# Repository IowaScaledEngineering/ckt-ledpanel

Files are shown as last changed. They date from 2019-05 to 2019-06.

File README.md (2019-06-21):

# CKT-LEDPANEL
Lithion Ion Battery-Powered Constant Current LED Boost Driver for Light Panel

## Project Background

Back in 2018, I came up with the idea for a battery-powered backlit display
cabinet to take with me to insulator shows.  The traditional solutions were
heavy cabinets with fluorescent tubes and ballasts that required line power.
By combining side-lit LED light panels intended for drop ceilings and high capacity lithium ion tool
batteries, building a small, light cabinet that would run entirely on battery power
was well within reach.

The CKT-LEDPANEL will drive a standard 30-38V panel at 300mA, which is more
than bright enough for a cabinet backlight.  It includes safety circuits to
prevent over-discharge of "20V" (5 series cell) lithium ion tool batteries,
such as those available from Dewalt.  It also provides convenient connectors
for an on/off switch and an 18VDC wall power supply input.

## Cabinet Construction Instructions

Instructions for constructing the cabinets and wiring everything up
(including the CKT-LEDPANEL) can be found [on my personal
website](https://www.ndholmes.com/projects/ins-cabinet/ins-cab-instructions-v1.0.pdf).

## License

The CKT-LEDPANEL is copyright 2019 by Nathan Holmes and Michael Petersen and manufactured by Iowa
Scaled Engineering.  The design is open hardware, and is shared under the
[Creative Commons Attribution-Share Alike
license](https://creativecommons.org/licenses/by-sa/4.0/legalcode).

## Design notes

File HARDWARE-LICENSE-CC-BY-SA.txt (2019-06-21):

The hardware design files for the Iowa Scaled Engineering I2C-RELAY16 are
open hardware, and licensed under the Creative Commons Attribution-Share
Alike license.

A copy can be found below, or from 
  http://creativecommons.org/licenses/by-sa/4.0/legalcode
-----------------------------------------------------------------------------

Creative Commons Attribution-ShareAlike 4.0 International Public License

By exercising the Licensed Rights (defined below), You accept and agree to
be bound by the terms and conditions of this Creative Commons
Attribution-ShareAlike 4.0 International Public License ("Public License").
To the extent this Public License may be interpreted as a contract, You are
granted the Licensed Rights in consideration of Your acceptance of these
terms and conditions, and the Licensor grants You such rights in
consideration of benefits the Licensor receives from making the Licensed
Material available under these terms and conditions.

Section 1 – Definitions.

    Adapted Material means material subject to Copyright and Similar Rights
that is derived from or based upon the Licensed Material and in which the
Licensed Material is translated, altered, arranged, transformed, or
otherwise modified in a manner requiring permission under the Copyright and
Similar Rights held by the Licensor. For purposes of this Public License,
where the Licensed Material is a musical work, performance, or sound
recording, Adapted Material is always produced where the Licensed Material
is synched in timed relation with a moving image.
    Adapter's License means the license You apply to Your Copyright and
Similar Rights in Your contributions to Adapted Material in accordance with
the terms and conditions of this Public License.
    BY-SA Compatible License means a license listed at
creativecommons.org/compatiblelicenses, approved by Creative Commons as
essentially the equivalent of this Public License.
    Copyright and Similar Rights means copyright and/or similar rights
closely related to copyright including, without limitation, performance,
broadcast, sound recording, and Sui Generis Database Rights, without regard
to how the rights are labeled or categorized. For purposes of this Public
License, the rights specified in Section 2(b)(1)-(2) are not Copyright and
Similar Rights.
    Effective Technological Measures means those measures that, in the
absence of proper authority, may not be circumvented under laws fulfilling
obligations under Article 11 of the WIPO Copyright Treaty adopted on
December 20, 1996, and/or similar international agreements.
    Exceptions and Limitations means fair use, fair dealing, and/or any
other exception or limitation to Copyright and Similar Rights that applies
to Your use of the Licensed Material.
    License Elements means the license attributes listed in the name of a
Creative Commons Public License. The License Elements of this Public License
are Attribution and ShareAlike.
    Licensed Material means the artistic or literary work, database, or
other material to which the Licensor applied this Public License.
    Licensed Rights means the rights granted to You subject to the terms and
conditions of this Public License, which are limited to all Copyright and
Similar Rights that apply to Your use of the Licensed Material and that the
Licensor has authority to license.
    Licensor means the individual(s) or entity(ies) granting rights under
this Public License.
    Share means to provide material to the public by any means or process
that requires permission under the Licensed Rights, such as reproduction,
public display, public performance, distribution, dissemination,
communication, or importation, and to make material available to the public
including in ways that members of the public may access the material from a
place and at a time individually chosen by them.
    Sui Generis Database Rights means rights other than copyright resulting
from Directive 96/9/EC of the European Parliament and of the Council of 11
March 1996 on the legal protection of databases, as amended and/or
succeeded, as well as other essentially equivalent rights anywhere in the
world.
    You means the individual or entity exercising the Licensed Rights under
this Public License. Your has a corresponding meaning.

Section 2 – Scope.

    License grant.
        Subject to the terms and conditions of this Public License, the
Licensor hereby grants You a worldwide, royalty-free, non-sublicensable,
non-exclusive, irrevocable license to exercise the Licensed Rights in the
Licensed Material to:
            reproduce and Share the Licensed Material, in whole or in part;
and
            produce, reproduce, and Share Adapted Material.
        Exceptions and Limitations. For the avoidance of doubt, where
Exceptions and Limitations apply to Your use, this Public License does not
apply, and You do not need to comply with its terms and conditions.
        Term. The term of this Public License is specified in Section 6(a).
        Media and formats; technical modifications allowed. The Licensor
authorizes You to exercise the Licensed Rights in all media and formats
whether now known or hereafter created, and to make technical modifications
necessary to do so. The Licensor waives and/or agrees not to assert any
right or authority to forbid You from making technical modifications
necessary to exercise the Licensed Rights, including technical modifications
necessary to circumvent Effective Technological Measures. For purposes of
this Public License, simply making modifications authorized by this Section
2(a)(4) never produces Adapted Material.
        Downstream recipients.
            Offer from the Licensor – Licensed Material. Every recipient of
the Licensed Material automatically receives an offer from the Licensor to
exercise the Licensed Rights under the terms and conditions of this Public
License.
            Additional offer from the Licensor – Adapted Material. Every
recipient of Adapted Material from You automatically receives an offer from
the Licensor to exercise the Licensed Rights in the Adapted Material under
the conditions of the Adapter’s License You apply.
            No downstream restrictions. You may not offer or impose any
additional or different terms or conditions on, or apply any Effective
Technological Measures to, the Licensed Material if doing so restricts
exercise of the Licensed Rights by any recipient of the Licensed Material.
        No endorsement. Nothing in this Public License constitutes or may be
construed as permission to assert or imply that You are, or that Your use of
the Licensed Material is, connected with, or sponsored, endorsed, or granted
official status by, the Licensor or others designated to receive attribution
as provided in Section 3(a)(1)(A)(i).

    Other rights.
        Moral rights, such as the right of integrity, are not licensed under
this Public License, nor are publicity, privacy, and/or other similar
personality rights; however, to the extent possible, the Licensor waives
and/or agrees not to assert any such rights held by the Licensor to the
limited extent necessary to allow You to exercise the Licensed Rights, but
not otherwise.
        Patent and trademark rights are not licensed under this Public
License.
        To the extent possible, the Licensor waives any right to collect
royalties from You for the exercise of the Licensed Rights, whether directly
or through a collecting society under any voluntary or waivable statutory or
compulsory licensing scheme. In all other cases the Licensor expressly
reserves any right to collect such royalties.

Section 3 – License Conditions.

Your exercise of the Licensed Rights is expressly made subject to the
following conditions.

    Attribution.

        If You Share the Licensed Material (including in modified form), You
must:
            retain the following if it is supplied by the Licensor with the
Licensed Material:
                identification of the creator(s) of the Licensed Material
and any others designated to receive attribution, in any reasonable manner
requested by the Licensor (including by pseudonym if designated);
                a copyright notice;
                a notice that refers to this Public License;
                a notice that refers to the disclaimer of warranties;
                a URI or hyperlink to the Licensed Material to the extent
                reasonably practicable;
            indicate if You modified the Licensed Material and retain an
indication of any previous modifications; and
            indicate the Licensed Material is licensed under this Public
License, and include the text of, or the URI or hyperlink to, this Public
License.
        You may satisfy the conditions in Section 3(a)(1) in any reasonable
manner based on the medium, means, and context in which You Share the
Licensed Material. For example, it may be reasonable to satisfy the
conditions by providing a URI or hyperlink to a resource that includes the
required information.
        If requested by the Licensor, You must remove any of the information
required by Section 3(a)(1)(A) to the extent reasonably practicable.
    ShareAlike.

    In addition to the conditions in Section 3(a), if You Share Adapted
Material You produce, the following conditions also apply.
        The Adapter’s License You apply must be a Creative Commons license
with the same License Elements, this version or later, or a BY-SA Compatible
License.
        You must include the text of, or the URI or hyperlink to, the
Adapter's License You apply. You may satisfy this condition in any
reasonable manner based on the medium, means, and context in which You Share
Adapted Material.
        You may not offer or impose any additional or different terms or
conditions on, or apply any Effective Technological Measures to, Adapted
Material that restrict exercise of the rights granted under the Adapter's
License You apply.

Section 4 – Sui Generis Database Rights.

Where the Licensed Rights include Sui Generis Database Rights that apply to
Your use of the Licensed Material:

    for the avoidance of doubt, Section 2(a)(1) grants You the right to
extract, reuse, reproduce, and Share all or a substantial portion of the
contents of the database;
    if You include all or a substantial portion of the database contents in
a database in which You have Sui Generis Database Rights, then the database
in which You have Sui Generis Database Rights (but not its individual
contents) is Adapted Material, including for purposes of Section 3(b); and
    You must comply with the conditions in Section 3(a) if You Share all or
a substantial portion of the contents of the database.

For the avoidance of doubt, this Section 4 supplements and does not replace
Your obligations under this Public License where the Licensed Rights include
other Copyright and Similar Rights.

Section 5 – Disclaimer of Warranties and Limitation of Liability.

    Unless otherwise separately undertaken by the Licensor, to the extent
possible, the Licensor offers the Licensed Material as-is and as-available,
and makes no representations or warranties of any kind concerning the
Licensed Material, whether express, implied, statutory, or other. This
includes, without limitation, warranties of title, merchantability, fitness
for a particular purpose, non-infringement, absence of latent or other
defects, accuracy, or the presence or absence of errors, whether or not
known or discoverable. Where disclaimers of warranties are not allowed in
full or in part, this disclaimer may not apply to You.
    To the extent possible, in no event will the Licensor be liable to You
on any legal theory (including, without limitation, negligence) or otherwise
for any direct, special, indirect, incidental, consequential, punitive,
exemplary, or other losses, costs, expenses, or damages arising out of this
Public License or use of the Licensed Material, even if the Licensor has
been advised of the possibility of such losses, costs, expenses, or damages.
Where a limitation of liability is not allowed in full or in part, this
limitation may not apply to You.

    The disclaimer of warranties and limitation of liability provided above
shall be interpreted in a manner that, to the extent possible, most closely
approximates an absolute disclaimer and waiver of all liability.

Section 6 – Term and Termination.

    This Public License applies for the term of the Copyright and Similar
Rights licensed here. However, if You fail to comply with this Public
License, then Your rights under this Public License terminate automatically.

    Where Your right to use the Licensed Material has terminated under
Section 6(a), it reinstates:
        automatically as of the date the violation is cured, provided it is
cured within 30 days of Your discovery of the violation; or
        upon express reinstatement by the Licensor.
    For the avoidance of doubt, this Section 6(b) does not affect any right
the Licensor may have to seek remedies for Your violations of this Public
License.
    For the avoidance of doubt, the Licensor may also offer the Licensed
Material under separate terms or conditions or stop distributing the
Licensed Material at any time; however, doing so will not terminate this
Public License.
    Sections 1, 5, 6, 7, and 8 survive termination of this Public License.

Section 7 – Other Terms and Conditions.

    The Licensor shall not be bound by any additional or different terms or
conditions communicated by You unless expressly agreed.
    Any arrangements, understandings, or agreements regarding the Licensed
Material not stated herein are separate from and independent of the terms
and conditions of this Public License.

Section 8 – Interpretation.

    For the avoidance of doubt, this Public License does not, and shall not
be interpreted to, reduce, limit, restrict, or impose conditions on any use
of the Licensed Material that could lawfully be made without permission
under this Public License.
    To the extent possible, if any provision of this Public License is
deemed unenforceable, it shall be automatically reformed to the minimum
extent necessary to make it enforceable. If the provision cannot be
reformed, it shall be severed from this Public License without affecting the
enforceability of the remaining terms and conditions.
    No term or condition of this Public License will be waived and no
failure to comply consented to unless expressly agreed to by the Licensor.
    Nothing in this Public License constitutes or may be interpreted as a
limitation upon, or waiver of, any privileges and immunities that apply to
the Licensor or You, including from the legal processes of any jurisdiction
or authority.

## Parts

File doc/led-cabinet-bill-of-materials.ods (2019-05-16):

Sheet: LED Cabinet BoM
Component | Mfgr | Part # | Source | Source SKU | Qty | Unit Price | Total Price
2x2 5000K 40W 4400 Lumen LED Panel | LTMate | LED-H500 | Amazon |  | 1 | $43.00 | $43.00
23-5/8" x 6" x 5/16" clear glass shelf | Dolle | 30104 | Home Depot | 289884 | 4 | $18.98 | $75.92
Ivar 33”x12” Shelf | Ikea | 101.665.75 | Ikea | 101.665.75 | 5 | $8.00 | $40.00
White shelf standard (72 inch) | Rubbermaid | FG4B9200WHT | Home Depot | 580898 | 2 | $3.98 | $7.96
Zinc shelf clips (25 pack) (or other Knape & Vogt 256-style clip) | Rubbermaid | FG4C2502ZINC | Home Depot | 559555 | 1 | $3.98 | $3.98
1/2” self-adhesive clear rubber dots (sheet of 100 - 4 per shelf) | Amazon | FD-SBP-CIR96 | Amazon | FD-SBP-CIR96 | 1 | $8.97 | $8.97
11/16” x 8ft pine outside corner moulding | Generic |  | Home Depot | 10001949 (or sim) | 1 | $8.57 | $8.57
3/4” x 8ft white PVC inside corner moulding | Generic |  | Home Depot | 901516 (or sim) | 1 | $3.53 | $3.53
Blue halo 19mm 12VDC latching switch | API-ELE | GQ19F-11EZ | Amazon |  | 1 | $8.52 | $8.52
Dewalt Battery Connector (DCB-20x power dock from msburko) | msburko | D20-PD | eBay | D20-PD | 1 | $14.99 | $14.99
Spare battery holder (3d printed) | Iowa Scaled Engineering | ACC-DW20V |  |  | 1 | $5.00 | $5.00
Control circuit / bracket | Iowa Scaled Engineering | CKT-LEDPANEL |  |  | 1 | $45.00 | $45.00
24V 1.5A wall power supply (5.5x2.1mm barrel jack, center positive) | Triad Magnetics | WSU240-1500 | Digikey | 237-1447-ND | 1 | $21.90 | $21.90
Total Cabinet Cost |  |  |  |  |  |  | $287.34
Dewalt 20V 5Ah battery | Dewalt | DCB205 | Various |  | 1 | $67.00 | $67.00
Dewalt DCB115 charger | Dewalt | DCB115 | Various |  | 1 | $35.00 | $35.00
Total Cabinet Cost + Battery + Charger |  |  |  |  |  |  | $389.34

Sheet: CKT-LEDPANEL BoM
Component | Mfr | Description | Qty | Unit Price | Total Price | RefDes
LT3519EMS-1 | Analog Devices | Boost DC-DC Converter | 1 | 3.14 | 3.14 | U1
TLV6710 | Texas Instruments | Dual comparator and reference (SOT23-6) | 1 | 1.78 | 1.78 | U2
LM5050MK-2 | Texas Instruments | Ideal Diode Controller (SOT23-6) | 1 | 1.53 | 1.53 | U3
DMC4050SSD-13 | Diodes Inc | Dual MOSFET (1N, 1P) in SO8 | 1 | 0.37 | 0.37 | U4
RCWE2512R820FKEA | Vishay | 0.82 ohm, 2W, 1% 2512 | 1 | 0.3 | 0.3 | R1
 | Generic | 340k, 1% Resistor (0805) | 2 | 0.01 | 0.02 | R2, R4
 | Generic | 30.1k 1% Resistor (0805) | 1 | 0.01 | 0.01 | R3
 | Generic | 10.0k 1% Resistor (0805) | 2 | 0.01 | 0.02 | R5,R9
 | Generic | 5.1k 1% Resistor (0805) | 1 | 0.01 | 0.01 | R6
 | Generic | 1.5k 1% Resistor (0805) | 1 | 0.01 | 0.01 | R7
 | Generic | 365k 1% Resistor (0805) | 1 | 0.01 | 0.01 | R8
 | Generic | 2k 1% Resistor (0805) | 1 | 0.01 | 0.01 | R10
CL32B475KBJNFNE | Samsung | 4.7uF 50V X7R/X5R (1210) | 2 | 0.13 | 0.26 | C1,C2
UCD1H470MCL1GS | Nichicon | 47uF 50V 6.3mm electrolytic capacitor | 2 | 0.44 | 0.88 | C1A,C3A
 | Generic | 1uF 50V X7R/X5R (0805) | 1 | 0.05 | 0.05 | C3
 | Generic | 0.1uF 16V X7R/X5R (0805) | 1 | 0.03 | 0.03 | C4
MSS1048-683 | Coilcraft | 4.7uH Inductor | 1 | 0.96 | 0.96 | L1
 | Generic | Red 0805 LED | 1 | 0.05 | 0.05 | D1
SK24 | Mulitple | Diode (SMB form factor) | 1 | 0.08 | 0.08 | D2
BZT52C10TQ-7-F | Diodes Inc | 10V Zener 5% (SOD123) | 1 | 0.08 | 0.08 | D3
3568 | Keystone | Mini-fuse holder | 1 | 1.03 | 1.03 | F1
1757242 | Phoenix Contact | 2-position 90 degree MSTBA shrouded header | 3 | 0.55 | 1.65 | J1,J2,J4
1757268 | Phoenix Contact | 4-position 90 degree MSTBA shrouded header | 1 | 1.08 | 1.08 | J3
1757019 | Phoenix Contact | 2-position screw terminal connector MSTB | 3 | 0.84 | 2.52 | J1,J2 (mating connector)
1757035 | Phoenix Contact | 4-position screw terminal connector MSTB | 1 | 3.96 | 3.96 | J3 (mating connector)
Total Parts Cost |  |  |  |  | 19.84

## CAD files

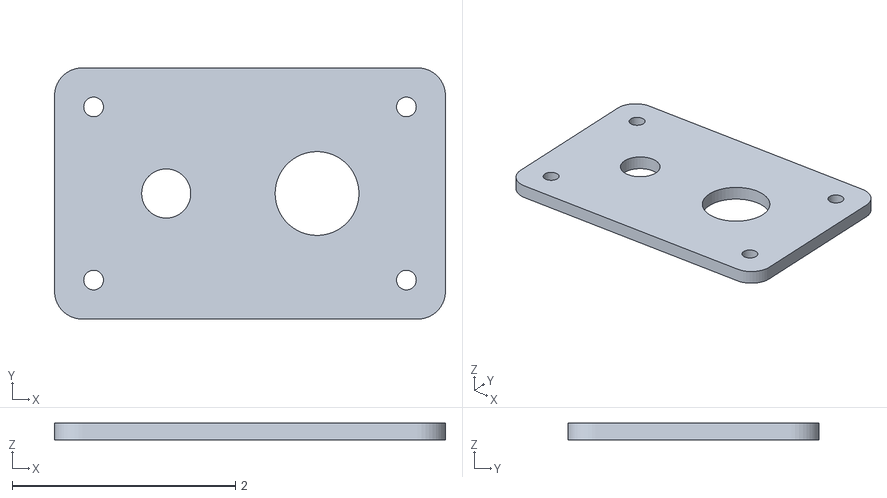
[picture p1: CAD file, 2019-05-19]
mech/insulator-cabinet-control-plate-v1.stl
3.50 x 2.25 x 0.15

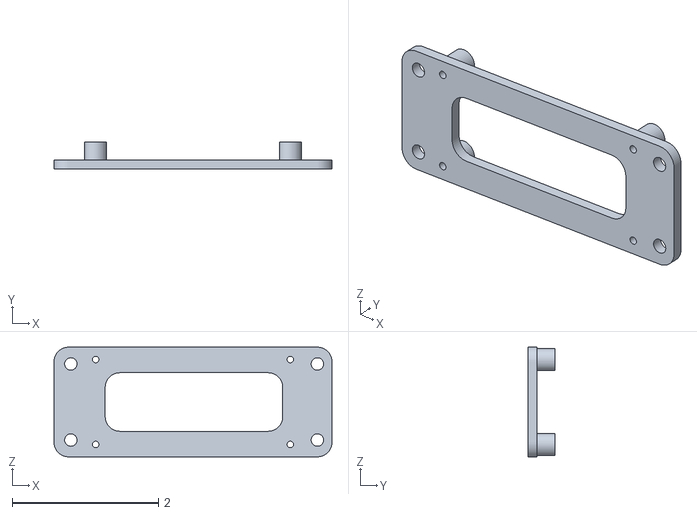
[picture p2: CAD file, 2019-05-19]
mech/ckt-ledpanel-mount v2.3.stl
3.80 x 0.375 x 1.50

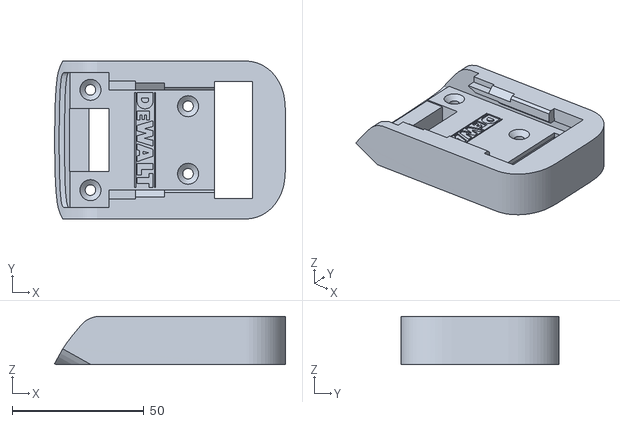
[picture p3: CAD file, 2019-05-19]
mech/dewalt-20v-holder.stl
87.6 x 59.8 x 18.3

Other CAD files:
mech/ckt-ledpanel-mount v2.3.f3d

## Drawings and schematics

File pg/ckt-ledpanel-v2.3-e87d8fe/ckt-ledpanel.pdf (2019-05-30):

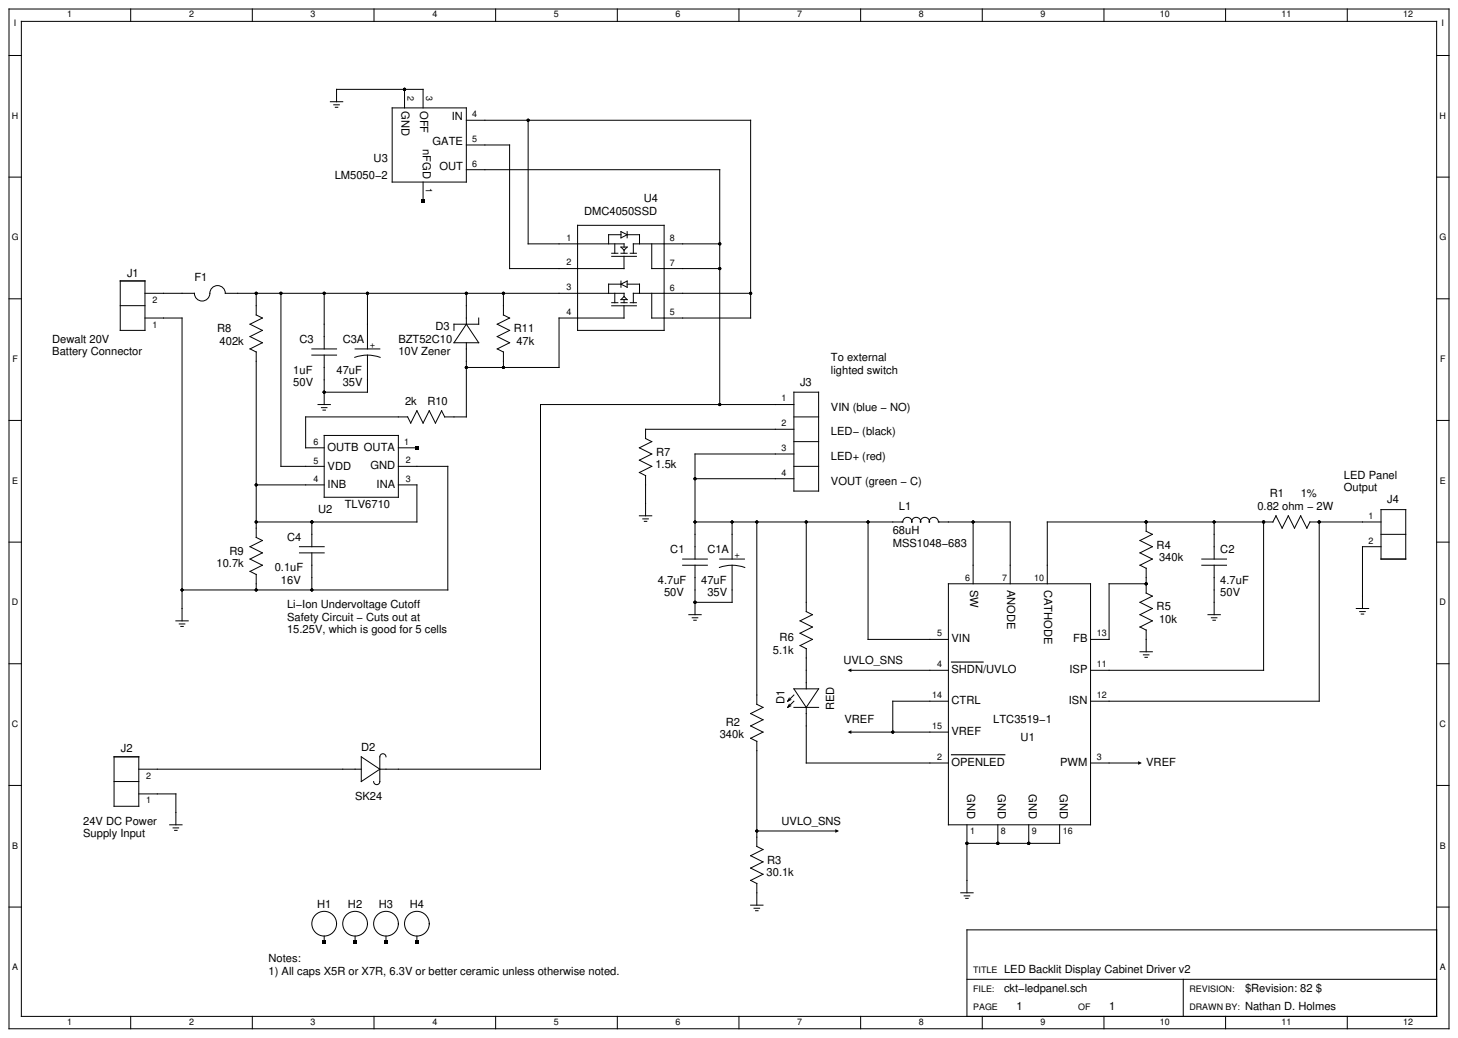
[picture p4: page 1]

Li−Ion Undervoltage Cutoff
Safety Circuit − Cuts out at
15.25V, which is good for 5 cells

Notes:
1) All caps X5R or X7R, 6.3V or better ceramic unless otherwise noted.

LED Backlit Display Cabinet Driver v2
ckt−ledpanel.sch

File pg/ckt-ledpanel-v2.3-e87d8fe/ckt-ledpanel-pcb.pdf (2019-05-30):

# ckt-ledpanel.pcb

# 1. Table of Contents (This Page) Created on Thu May 30 14:40:21 2019

# 2. top 3. bottom 4. outline 5. plated-drill 6. componentmask 7. soldermask 8. topsilk 9. bottomsilk 10. toppaste 11. topassembly 12. bottomassembly 13. fab

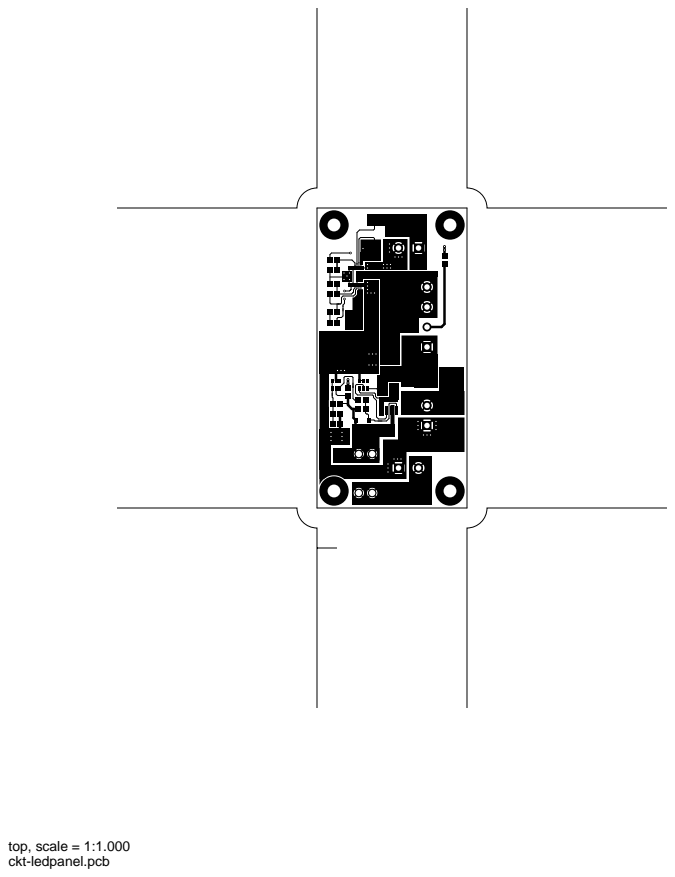
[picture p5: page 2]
top, scale = 1:1.000

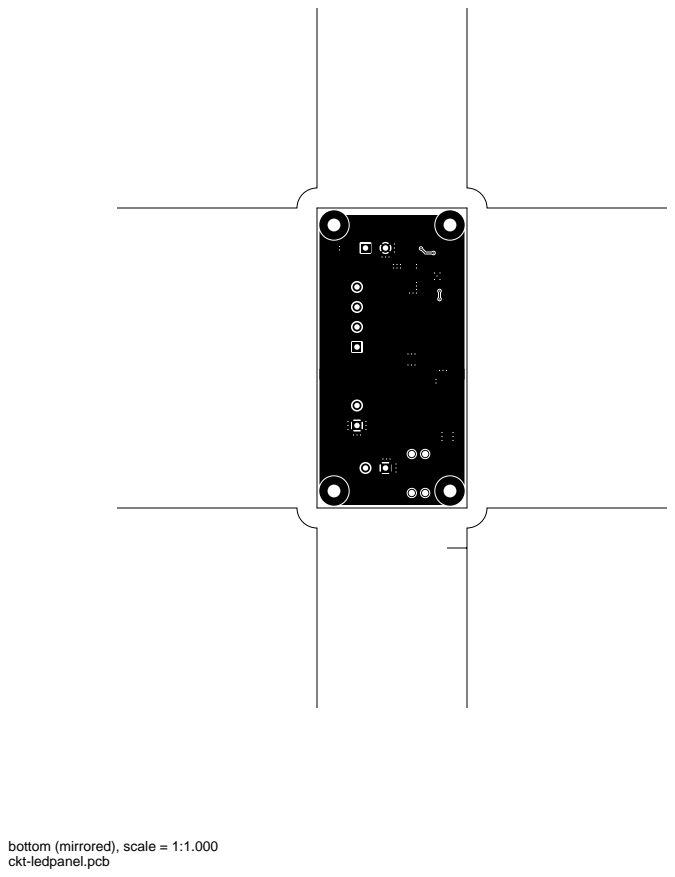
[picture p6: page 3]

bottom (mirrored), scale = 1:1.000

outline, scale = 1:1.000

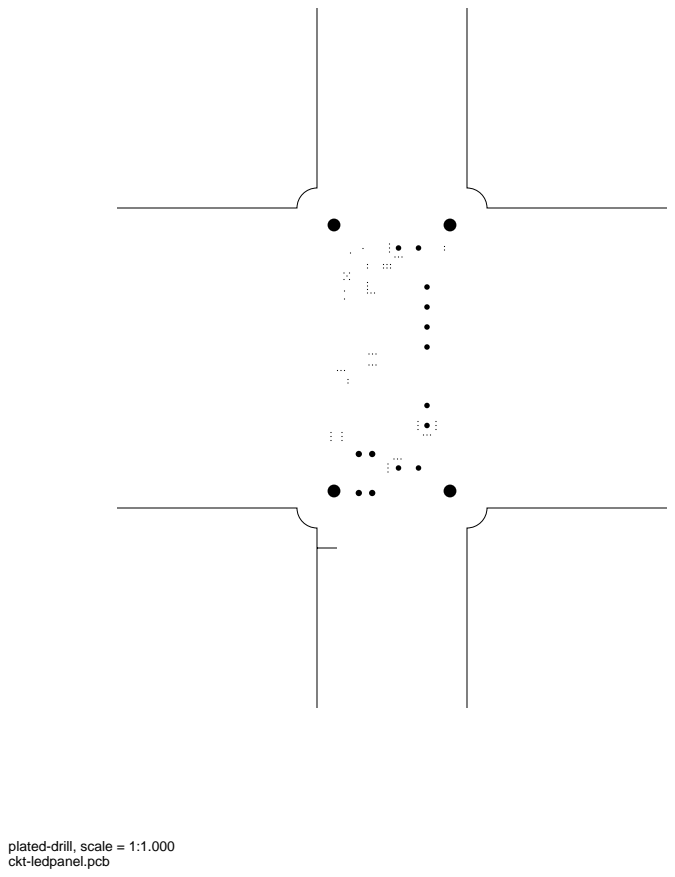
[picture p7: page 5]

plated-drill, scale = 1:1.000

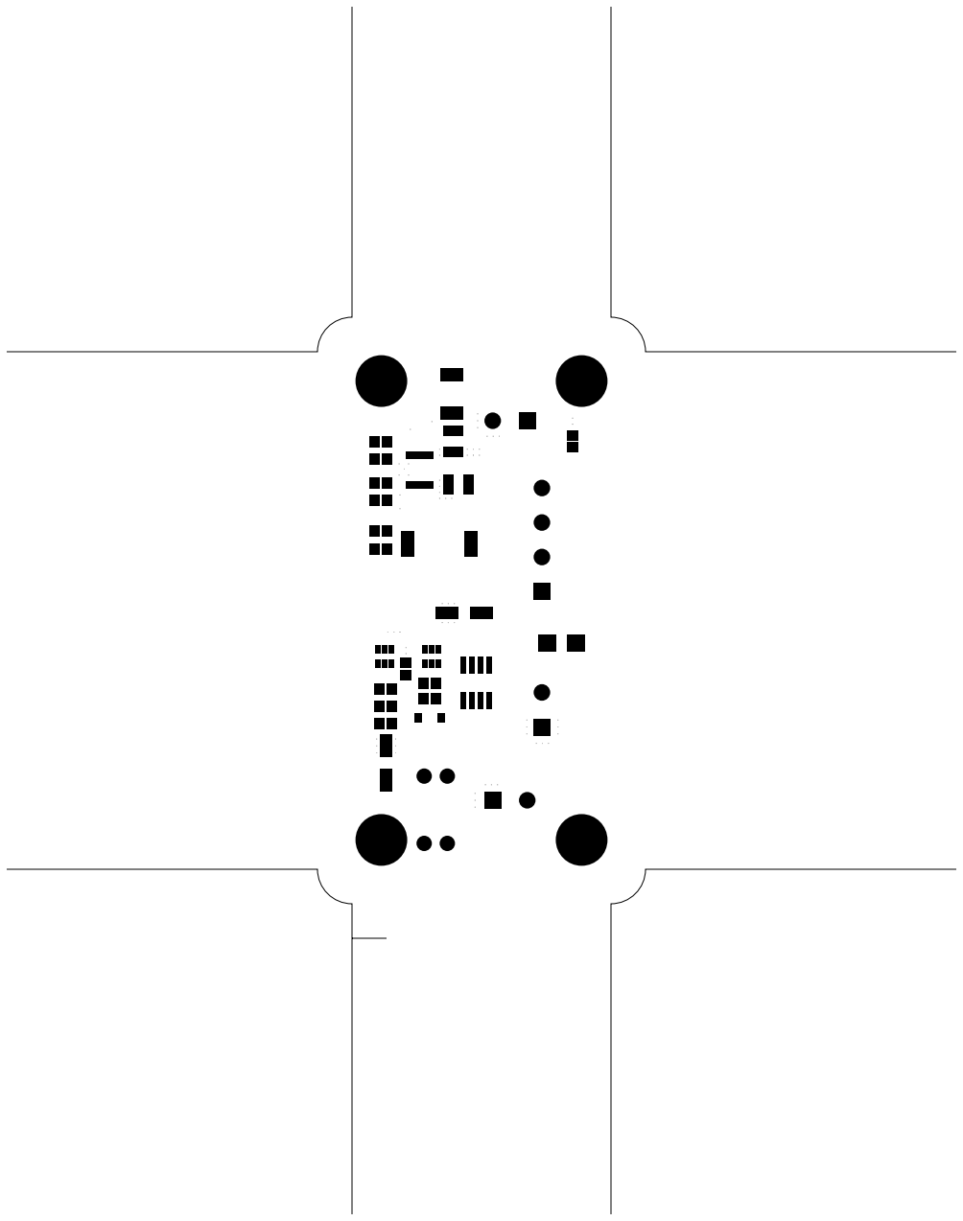
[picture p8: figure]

topmask, scale = 1:1.000

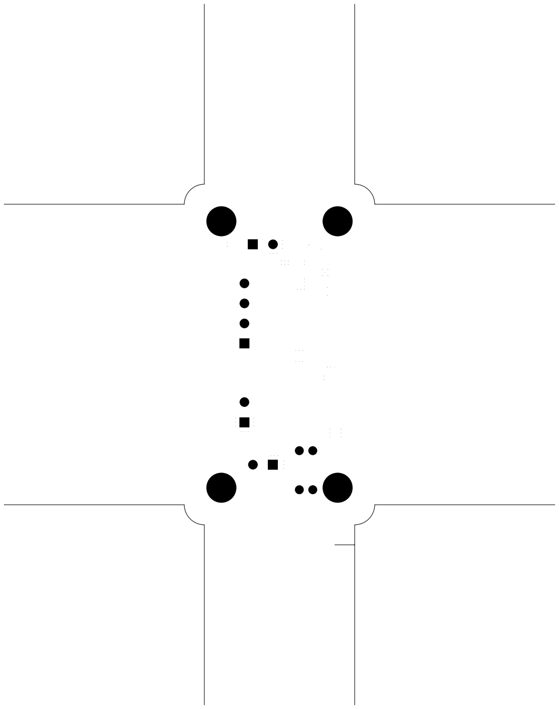
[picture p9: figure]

bottommask (mirrored), scale = 1:1.000

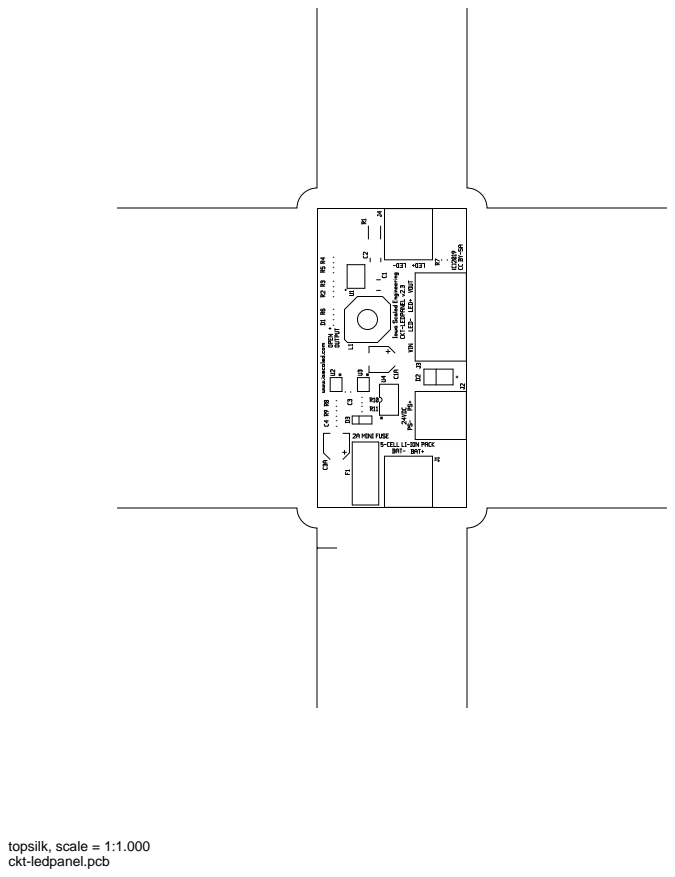
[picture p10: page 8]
topsilk, scale = 1:1.000

bottomsilk (mirrored), scale = 1:1.000

toppaste, scale = 1:1.000

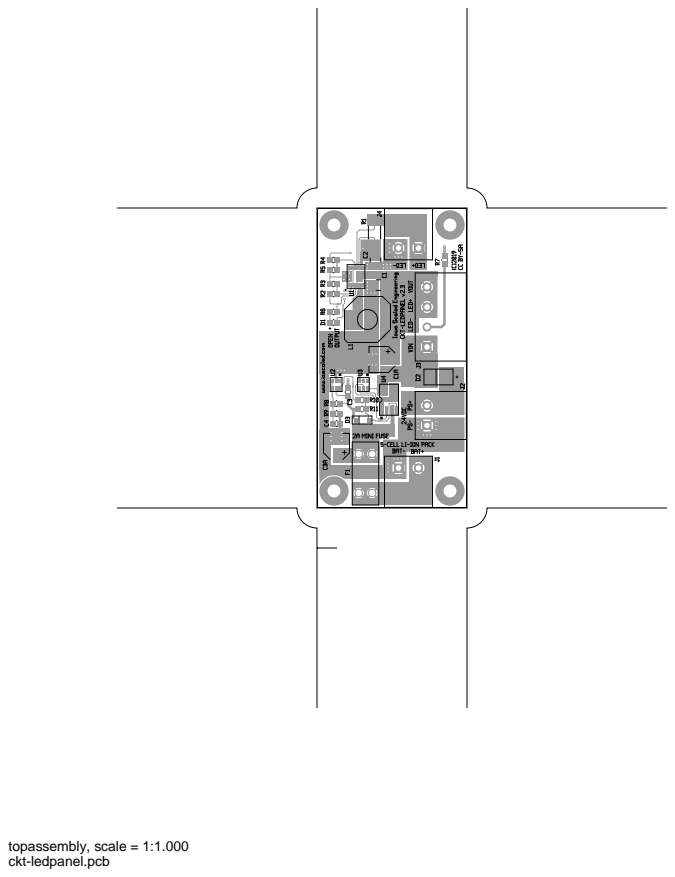
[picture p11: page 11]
topassembly, scale = 1:1.000

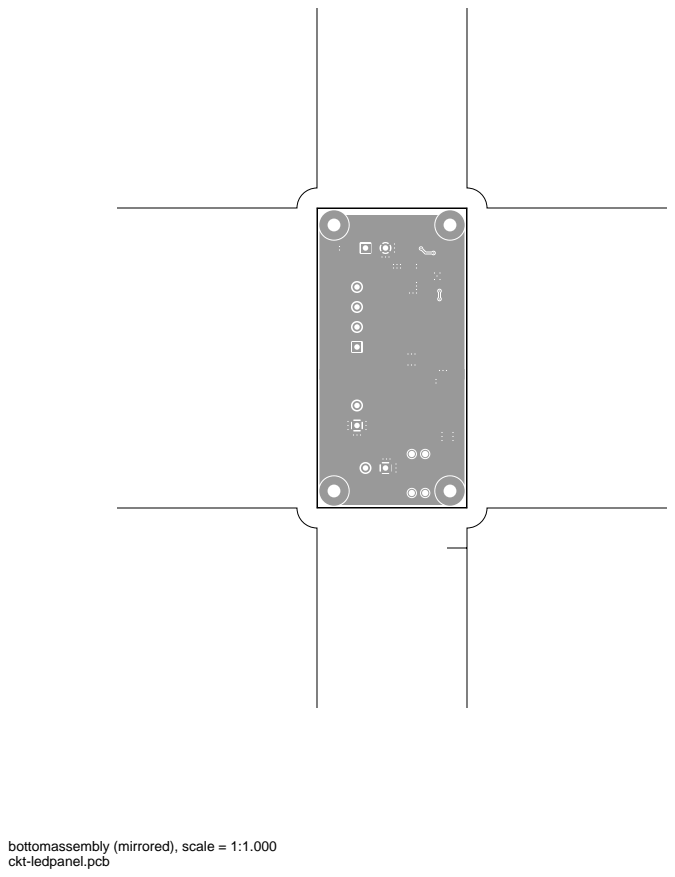
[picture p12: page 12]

bottomassembly (mirrored), scale = 1:1.000

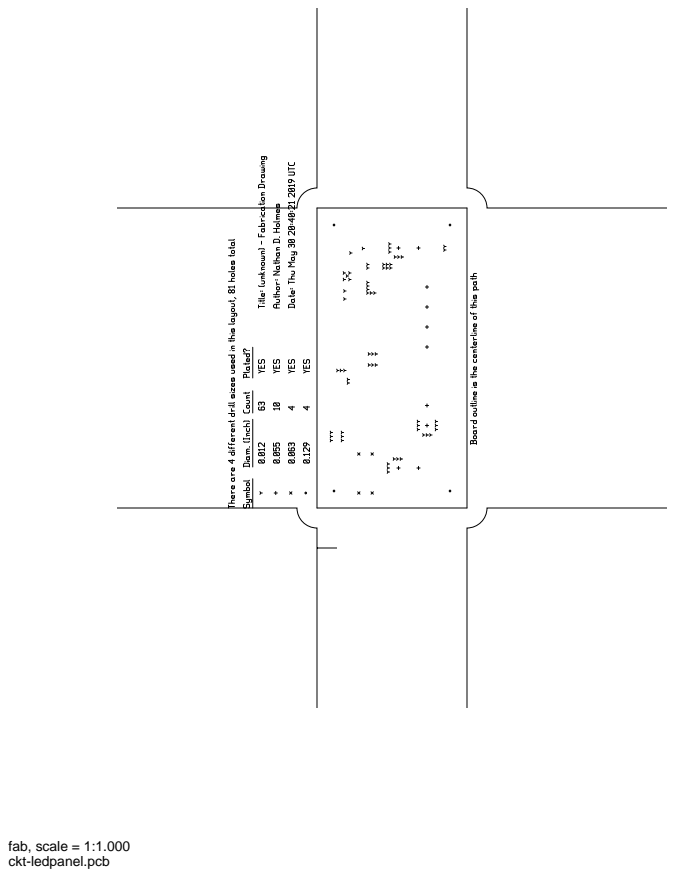
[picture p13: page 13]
fab, scale = 1:1.000

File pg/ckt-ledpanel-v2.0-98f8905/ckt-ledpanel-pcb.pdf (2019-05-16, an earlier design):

# ckt-ledpanel.pcb

# 1. Table of Contents (This Page) Created on Wed Apr 17 20:51:52 2019

# 2. top 3. bottom 4. outline 5. plated-drill 6. componentmask 7. soldermask 8. topsilk 9. bottomsilk 10. toppaste 11. topassembly 12. bottomassembly 13. fab

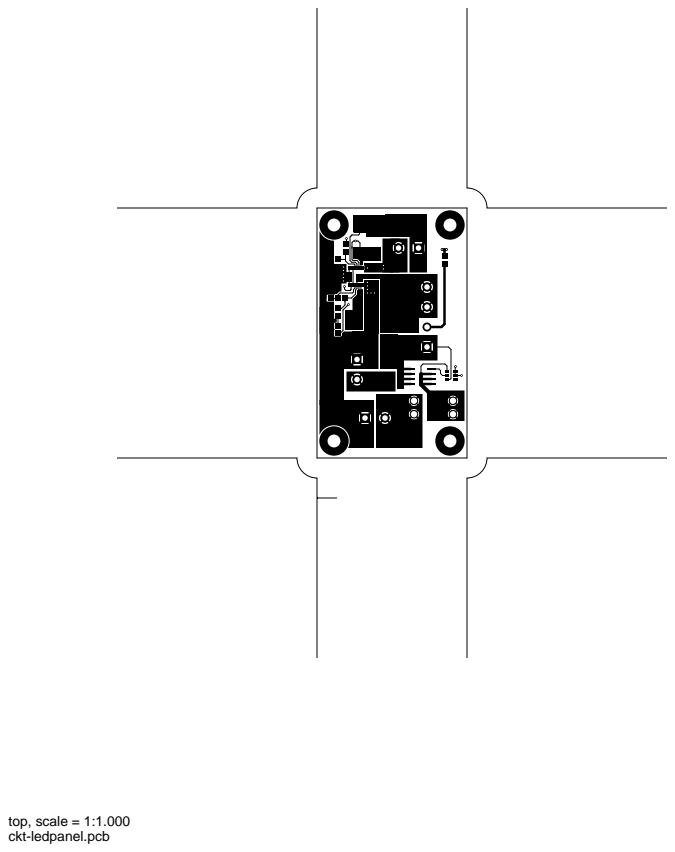
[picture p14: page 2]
top, scale = 1:1.000

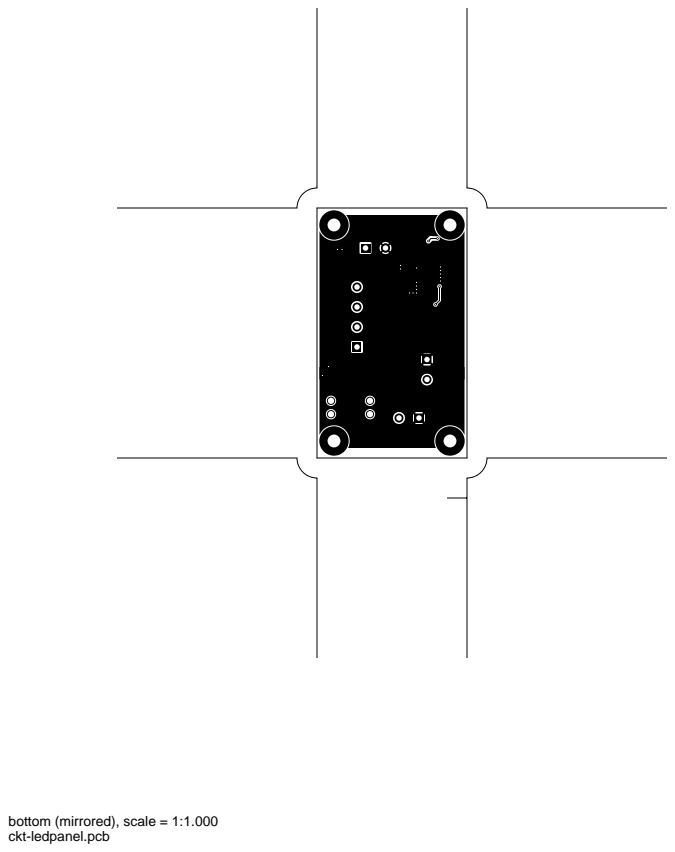
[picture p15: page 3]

bottom (mirrored), scale = 1:1.000

outline, scale = 1:1.000


plated-drill, scale = 1:1.000


topmask, scale = 1:1.000


bottommask (mirrored), scale = 1:1.000

topsilk, scale = 1:1.000


bottomsilk (mirrored), scale = 1:1.000

toppaste, scale = 1:1.000

topassembly, scale = 1:1.000


bottomassembly (mirrored), scale = 1:1.000

fab, scale = 1:1.000

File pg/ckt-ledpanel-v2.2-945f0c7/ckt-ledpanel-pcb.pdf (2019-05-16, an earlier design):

# ckt-ledpanel.pcb

# 1. Table of Contents (This Page) Created on Tue May 7 10:42:47 2019

# 2. top 3. bottom 4. outline 5. plated-drill 6. componentmask 7. soldermask 8. topsilk 9. bottomsilk 10. toppaste 11. topassembly 12. bottomassembly 13. fab

top, scale = 1:1.000


bottom (mirrored), scale = 1:1.000

outline, scale = 1:1.000


plated-drill, scale = 1:1.000


topmask, scale = 1:1.000


bottommask (mirrored), scale = 1:1.000

topsilk, scale = 1:1.000

bottomsilk (mirrored), scale = 1:1.000

toppaste, scale = 1:1.000

topassembly, scale = 1:1.000


bottomassembly (mirrored), scale = 1:1.000

fab, scale = 1:1.000

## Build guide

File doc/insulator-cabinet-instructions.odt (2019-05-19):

Building a Portable, Back-lit, Battery Powered Insulator Display Case

Step 1: Choose two of the Ikea Ivar shelves (or similar boards) to be the top and bottom. If you have one with a particularly ugly side, choose it as one of these two, as one will be the bottom that nobody will ever see.

If the labels aren’t easy to remove, use a heat gun on low to soften them up.

Cut the ends off each board to form two boards 28-3/4” in length.

Step 2: Choose two more Ivar shelves for the sides. Again, remove the price stickers and cut these to 24-3/4” long.

Step 3: Using a straight-sided, 3/4” router bit, cut two dado channels that are exactly 1/4” deep in one side of the top and bottom boards. The inner edge of each channel should be 2-1/4” from the edge of the board, which should leave 24-1/4” between the inner edges.

Step 4: Apply a thin line of wood glue to the end of each of the side panels cut in in step 2, and firmly insert into the dado joints in the top and bottom to form a square frame. Use 90 degree corner clamps to make all four joints square.

Once I have all joints seated and aligned, I like to use a 16ga finishing nail gun to drive 2-3 nails into each joint as well to help hold everything in position.

Wait until this is thoroughly dried before proceeding to step 8. You can work on steps 5-7 in the meantime.

Step 5: Using the final Ivar shelf, cut the ends off and leave at least 26” of board.

Step 6: Use a table saw to rip 3” off each side of the shelf. Once these are ripped, discard the center section. These edge pieces will be installed in the back of the shelf for strength and to provide protection for the electronics (top) and a compartment to store things (bottom). Cut each piece (working around any ugly parts) to 24-1/4” long.

Step 7: Pick one of the two pieces from step 6 that looks good with the finished edge down (and the ripped edge up). This will become the top board. Again with the finished edge down, mark two center points that are 3” and 4-3/8” in from the right side and on a line 1-1/2” down from the top. Use a good sharp 1” Forstner bit to drill two adjacent holes using these two center points. These will be where the wires for the power switch and power supply jack pass through the top board.

Step 8: Choose a side of the cabinet to be the front and the top. Using the board we made in step 7, run a thin strip of wood glue along the top cut edge (not the finished edge, at the bottom) and install into the top rear of the cabinet. Remember, the switch holes should be on the right as you face the back of the cabinet. The face of this rear switch board should be flush with the end of the bevel on the finished edges of the sides and top. Secure using clamps and drive two 16ga finishing nails through the side into each end and three more evenly spaced from the top.

Step 9: Repeat with the other piece cut in step 6, except install it at the bottom of the back. The finished edge should go up, and the ripped edge should go down. Again, a thin bead of glue on the bottom edge and nails from the sides and bottom to secure it.

Step 10: Cut two 24-1/4” pieces and two 21” pieces of corner molding. Test fit the two 24-1/4” pieces into the sides of the box to verify that they fit between the top and bottom boards. If they do not, trim them slightly until they do.

Step 11: Using a 5/64” drill bit, drill three holes through the side of each piece of corner molding that will attach to the cabinet walls. Make one hole in the center, and then make two more, each at approximately 1” from the end.

Step 12: Using a 220 grit sanding block (or similar), sand any blemishes from the inside of the box frame.

Step 13: Carefully and lightly mark 7” back from the front of the cabinet on the inside sides and inside top/bottom. I recommend one mark at the center and a couple more out towards the ends. These will mark the front edges of the corner molding installation.

Step 14: Apply a very small amount of wood glue to the side of each L-channel that will attach to the interior box frame. Carefully set each one in place against the marks so that the front edge is 7” from the front of the cabinet. Using 18x5/8” wire nails and a small tack hammer, carefully drive these into place to hold the corner molding.

Step 15: Using stainable wood putty, fill any and all nail holes in the outside surface of the cabinet. Wait for these and all joints to dry thoroughly.

Step 16: Sand the puttied holes and any blemishes on the cabinet, preparing it for stain.

Step 17: Apply a coat of stain (color of your preference) to the cabinet. Wait until thoroughly dry (usually 24-36 hours). My go-to color is Minwax Golden Pecan #245.

Step 18: Apply one coat of Minwax Polyacrylic or similar per manufacturer instructions. I prefer polyacrylic because it forms a nice hard surface immediately after curing, doesn’t run on vertical surfaces, and dries perfectly clear. I typically don’t put a coat on the bottom of the cabinet base, just because there’s no point. Once that coat has dried, apply another. Wait for that to dry, sand lightly but thoroughly with a 220 grid sanding block (or similar) and apply a third coat.

Step 19: Take each of the 72” white shelf standards and measure 24” from the ends. The goal is to keep one factory end on each upright. Using a Dremel and a carbon fiber cutoff disk, cut four 24” standards (one from each end of each 72” piece). Be sure to wear eye protection! Once each is cut, use a Dremel grinding stone bit to grind down any sharp metal left on each cut end.

Step 20: Using a fine point Sharpie or other marking tool, mark points at 1-5/8” and 5-1/4” in from the front edge of the cabinet on the inside of each side board. Mark them near the top and near the bottom of the inside of each side. This is where the front edge of the standards will go.

Step 21: Using 18-8 stainless #2 round head metal screws (McMaster part 93406A075 or similar), secure each standard to the side. The factory cut end should always be down and flush against the bottom board, and the front-most edge of the standard should be against the marks you added in step 20. Put the bottom screw in the holes pictured to avoid conflicting with common places to put shelf clips.

Step 22: Cut two pieces of white PVC inside corner molding, each 23-3/4” long.

Step 23: Using a 3/16” drill bit, drill three holes through one edge of each piece from step 22. Make the holes perpendicular to the bottom rear surface. The holes should be an inch in from each end, and in the center (11-3/4” from either end).

Step 24: Unbox the LTMate 2’x2’ 5000K LED panel. Remove the screw from the wiring compartment of the ballast box on the back. Depress the tiny tab above the red and white wires where they connect to the board, and carefully pull each wire out of the terminal block. When both wires are free, remove the three screws holding the ballast box to the LED panel. Discard the ballast and reinsert the mounting screws into the panel.

Step 25: Install the LED panel into the front of the cabinet, making sure the wires are near the switch holes in the upper right rear of the cabinet.

Step 26: Once the panel is seated into the corner molding channel, take a piece of the inside corner molding from step 22-23 and place it at the bottom edge of the panel so that the holes go down into the bottom board of the cabinet. Make sure the molding is securely against the bottom board and against the light panel, and is roughly centered. Using 3/4” #10 round or pan head stainless metal screws (or similar), screw the molding down. I typically start with the center hole and then do the two ends.

Step 27: Repeat with the other piece of molding, but against the top edge of the panel.

Step 28: After laying down some padding (old towels, etc.) for the cabinet to safely sit in, flip the cabinet over such that the top surface is down. That will make all of the electrical work to come much easier.

Step 29: Connect two position terminal connector to the end of the LED panel wires. You’ll probably need to strip a bit more insulation (about 1/4” of wire should be exposed) than was done to connect to the original ballast. If you hold the connecter with the pins pointing left and screws up as shown, the positive (usually red) wire should be connected to the bottom terminal, and the negative (usually white or black) should be connected to the top. Be very, very sure that the exposed conductors are completely within the terminal block and that there are no exposed strands hanging out that could touch anything. Firmly tighten the screws and give each wire a little tug afterwards to make sure it’s firmly held.

Step 30: Mount the PCB for the CKT-LEDPANEL to the 3D-printed ABS bracket using four 18-8 stainless #2 round head metal screws (the same type as from step 21). Connect the LED terminal block to the board’s LED connector and position on the underside of the cabinet top as shown. There should be enough slack in the LED panel wires so that the terminal block can be easily connected and removed. Once you’re happy with the position, use four #8 x 1/2” truss-head Philips lath screws to secure it in place.

Step 31: Cut two 10 inch pieces of #18 AWG stranded copper wire of two different colors. The colors don’t really matter, but you’ll need the colors to clearly note which line is positive (the center of the barrel jack) and which is negative (the ring, or outer edge, of the barrel jack). In this example, I used blue (positive) and white (negative) because it’s the first thing I found scrounging around my workbench. Plus, blue and white are distinct from the other sets of wires coming into the control board, so it helps keep them straight.

Once you have the wires cut, solder them into the barrel jack. You should strive for nice neat solder joints, with an absolute minimum amount of wire outside the insulation. This helps prevent shorts. Once both are firmly soldered, use shrink wrap to insulate all around them.

Step 32: Install the barrel jack and the 19mm power switch into the 3D-printed control faceplate.

Step 33: Slip the wires from the barrel connector through the 1” hole nearest the edge of the case and line up the switch. Once you have the panel nicely seated and square, use four #8 x 1/2” truss-head Philips lath screws to attach it to the back of the case.

Step 34: Connect the harness from the 19mm 12V LED halo power switch to the 4-position terminal connector. If the connector is pointing to the right as shown in the picture, the wires should be the “Normally Open” wire on top (blue), the LED negative lead next (black), the LED positive lead (red), and finally the “Common” terminal (green) on the bottom. Note that there’s no color code standard here – your harness may differ from mine, so be sure to check the pin functions.

If your harness has a “Normally Closed” wire (yellow in this case), trim it at the power switch connector. It won’t be used.

Step 35: Trim the wires from the barrel jack to nicely align with the control PCB. Connect them to a 2-position terminal connector. The positive (barrel jack center – blue in the picture) wire should go into the position nearest the 4-position connector, and the negative (barrel jack outside – white in the picture) should go in the other side nearer the battery connector and fuse.

As with step 29, be very, very sure that the exposed conductors are completely within the terminal block and that there are no exposed strands hanging out that could touch anything. Firmly tighten the screws and give each wire a little tug afterwards to make sure it’s firmly held.

Step 36: Install the harness between the 19mm power switch and the PCB. I suggest inserting the terminal connector into the PCB first, and then looping the wires around to plug into the switch.

Step 37: Position the Dewalt 20V battery connector (D20-PD-14) on the inside of the cabinet wall nearest the control PCB. I typically center it front-to-back (so the center line is about 2” from the back edge) and place it so that there’s a 2.5-3 inch gap between the bottom (currently facing up) of the back board with the switches and the top (currently facing down, the end with wires) of the battery holder. This allows you to stick a finger in to hit the battery status button and see how much power you have left.

Once you’ve found the right spot, use a black fine point Sharpie to mark the center of the two mounting holes. Using a small (3/64” or similar) drill bit, drill two pilot holes about 3/8” of an inch deep. Be very careful not to drill all the way through the case and have an unsightly hole through the finished exterior surface.

Use #8 x 3/4” flathead Philips wood screws to secure the battery holder to the side wall.

Step 38: Trim the battery leads to a comfortable length (leave some excess to allow plugging and unplugging, but it not too much) and strip approximately 1/4” of wire at the end of each. The red (positive) battery lead should go in the terminal block connector closest to the back of the case (labeled BAT+ on the PCB), and the black (negative) battery lead should go in the terminal block connector closest to the LED panel (labeled BAT- on the PCB).

Be very, very sure that the exposed conductors are completely within the terminal block and that there are no exposed strands hanging out that could touch anything. Firmly tighten the screws and give each wire a little tug afterwards to make sure it’s firmly held.

Once you’ve plugged in the connector, double-check your work. This is the unfused, unprotected side of the circuit. You must be extremely careful with your work here, as any short will be dangerous and spectacular to say the least. These batteries are capable of producing 100 amps or more if shorted, which is more than enough to incinerate these small wires and set surrounding things on fire. Not only that, but the heat generated in the battery from such a short, if maintained long enough, can be enough to cause the battery itself to erupt in a ball of nearly inextinguishable fire.

There aren’t words enough to tell you how careful to be here. Lithium batteries are safe if made well and used correctly. If abused, they’re extremely dangerous.

Step 39: (Optional) At the opposite end of the interior case wall from the active battery connector, install the 3D-printed dummy Dewalt 20V battery holder. This is handy to sometimes have two batteries, since a 5Ah battery will typically only go for about 8 hours. This way you can use two smaller batteries, or have a backup on hand just in case.

Again as in step 37, figure out about where you want it, mark it, drill pilot holes with a small drill bit, and mount with #8 x 3/4” flathead Philips wood screws.

Step 40: Recheck all of your electrical work a second time. Make sure no metal tools have been left behind where they could short the PCB. Make sure the power switch is off. Connect the 24V power supply to the barrel jack and click on the power switch. If you’ve done everything correctly, the blue halo around the switch should light and most importantly, the panel should glow with an even white light. (Believe it or not, it’s much safer to try starting things up on the small wall power supply than on the tool battery.)

If that all goes well, turn the light off, disconnect the wall power adapter and carefully insert a battery. Again, click the power switch and make sure everything powers up correctly.

Step 41: Turn the cabinet off, take out the battery (just in case a loose screw or something might come in contact with the board), and turn the cabinet back over. Insert metal shelf clips in all four shelf standards. My cabinet has four shelves and the top surface of the clips are at 1-1/2”, 7”, 12-1/4”, and 17” from the bottom. Place a clear rubber dot on the top surface of each clip, and then carefully insert the glass shelves.

Enjoy your new portable, backlit display cabinet!

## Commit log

2018-03-12 First cut of a design for the LED power supply
    [ckt-ledpanel.sch]
2018-03-12 Change UVLO resistor divider to cut off at 3.1V per cell falling, 3.25V rising
    [ckt-ledpanel.sch]
2018-03-12 Add files via upload
    Spreadsheet used to calculate a few key values in the circuit
    [ckt-ledpanel-calculations.ods]
2018-03-12 Move calculation spreadsheet to doc directory
    [ckt-ledpanel-calculations.ods]
2018-03-12 Update the part number on the LT3519-1 to reflect that it's the 1MHz version
    [ckt-ledpanel.sch]
2018-03-12 Update to add open circuit LED
    [ckt-ledpanel.sch]
2019-04-15 New v2 PCB that has dual inputs and a connector for the power switch
    [ckt-ledpanel.sch]
2019-04-15 Change shut resistor value and FET part number First FET I picked didn't have enough Rds for the LM5050
    [ckt-ledpanel.sch]
2019-04-18 Add pg of v2.0
    [ckt-ledpanel.bottom.gbr, ckt-ledpanel.bottommask.gbr, ckt-ledpanel.bottompaste.gbr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]
2019-04-30 Add comparator to drive the switch LED and cut it off in UVLO
    [ckt-ledpanel.sch]
2019-04-30 Finish up v2.1 schematic and PCB redesign
    [ckt-ledpanel.sch]
2019-05-01 Version 2.2 - maybe something I finally like
    [ckt-ledpanel.sch]
2019-05-01 Now finally v2.2 - I think I actually like the circuit design on this one.
    [ckt-ledpanel.sch]
2019-05-06 PCB layout corrections per MDP
2019-05-06 Edits to v2.2 - add input electrolytics, minor edits per Michael's DR
    [ckt-ledpanel.sch]
2019-05-07 PG out v2.2
    [ckt-ledpanel.bottom.gbr, ckt-ledpanel.bottommask.gbr, ckt-ledpanel.bottompaste.gbr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]
2019-05-14 Add BoM for the whole LED cabinet and board
    [led-cabinet-bill-of-materials.ods]
2019-05-16 Initial checkin of assembly instructions from handwritten notes
2019-05-18 Fix using the wrong comparator output
    [ckt-ledpanel.sch]
2019-05-19 Add mechanical directory with brackets for the ckt-ledpanel v2.2+, the back control panel for the finished cabinet, and the Dewalt-compatible battery holder clip
    [ckt-ledpanel-mount v2.3.f3d, ckt-ledpanel-mount v2.3.stl, dewalt-20v-holder.stl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]
2019-05-22 Fix the input divider ratio to deal with the fact we're now using output B, which doesn't go high until Vref-Vhys, or 0.3945V (typical) We want that to cut out the battery at roughly 3.05V/cell, or 1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
    [ckt-ledpanel.sch]
2019-05-30 Add pg directory for v2.3
    [ckt-ledpanel.bottom.gbr, ckt-ledpanel.bottommask.gbr, ckt-ledpanel.bottompaste.gbr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]
2019-05-30 Oops, got a bad pdf for the schematic on v2.3
